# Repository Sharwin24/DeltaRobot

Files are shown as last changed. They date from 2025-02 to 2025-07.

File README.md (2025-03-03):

# DeltaRobot
Author: Sharwin Patil (*2025 MSR Winter Project*)

<div style="text-align: center;">
  Delta Robot Workspace
</div>

# ROS Package Structure

## Trajectory Generator
The `deltarobot_control` package is responsible for generating trajectories for the robot to follow. Currently, some hardcoded trajectories are baked into the package, but the package will be extended to offer parametric trajectory generation, resulting in position-velocity trajectories.

## Kinematics Solver
The `deltarobot_kinematics` package enables several kinematic capabilities for any delta robot. The package accepts a config file that specifies the robot's geometry, link lengths, and joint limits. Forward and Inverse Kinematics are implemented here as well as the Jacobian for creating joint-velocity trajectories from position trajectories.

## Motor Controller
The `deltarobot_motorcontrol` package is responsible for interfacing (using the hardware) with the 3 motors controlling the robot. This package implements
interfacing with dynamixel motors but can be extended to other motor types as long as the inter-node connections are maintained.

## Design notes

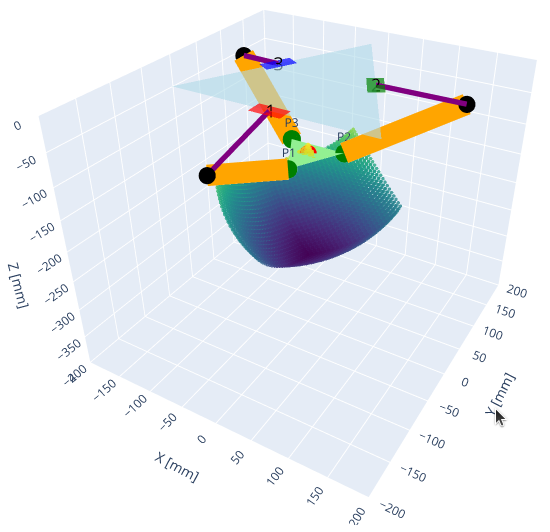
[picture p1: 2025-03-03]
images/workspace.png

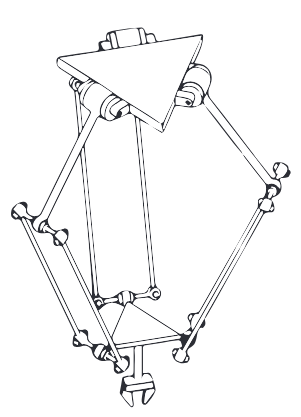
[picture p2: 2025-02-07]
images/delta_robot_modern_robotics.png

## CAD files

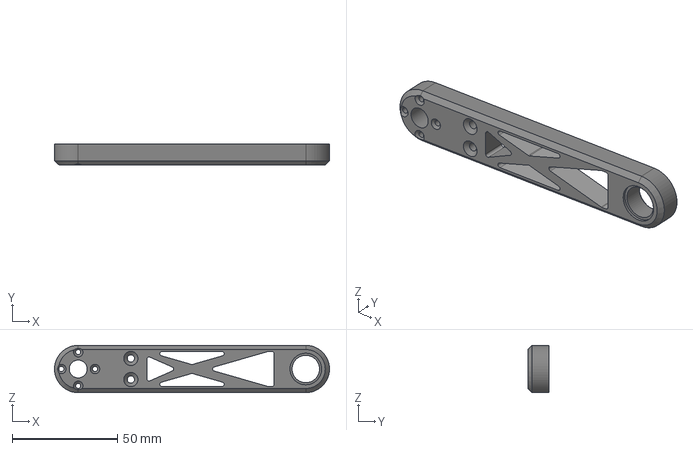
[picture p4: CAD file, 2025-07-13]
3D Printed Parts/Active Link.step
130.5 x 10.0 x 22.5 mm

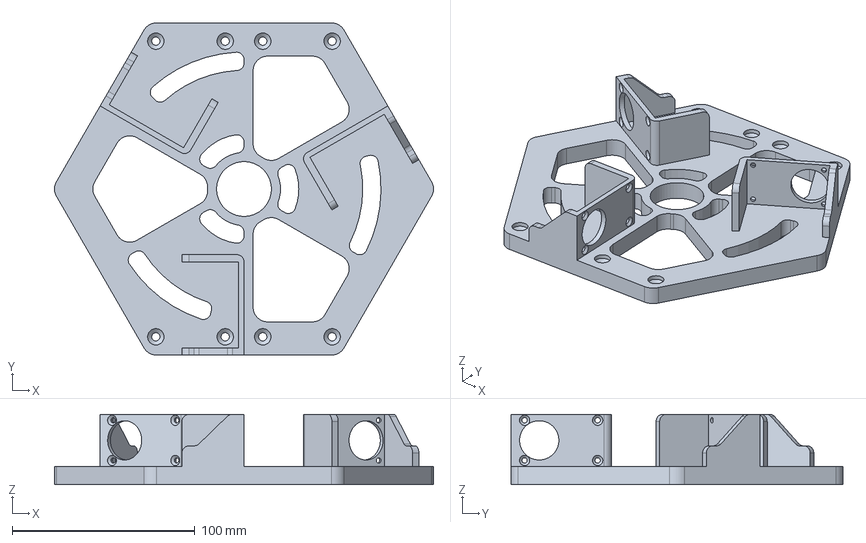
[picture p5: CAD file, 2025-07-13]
3D Printed Parts/Motor Base.step
207.5 x 181.9 x 38.5 mm

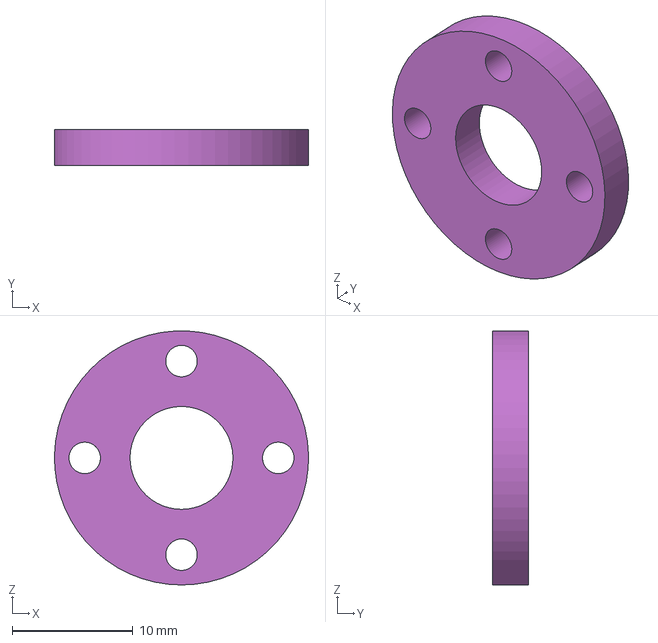
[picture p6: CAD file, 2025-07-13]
3D Printed Parts/Motor Spacer.step
21.0 x 3.00 x 21.0 mm

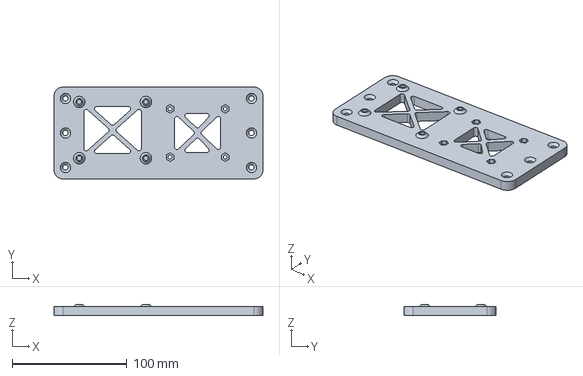
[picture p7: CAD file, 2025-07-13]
3D Printed Parts/Electronics Platform.step
181.9 x 80.0 x 10.0 mm

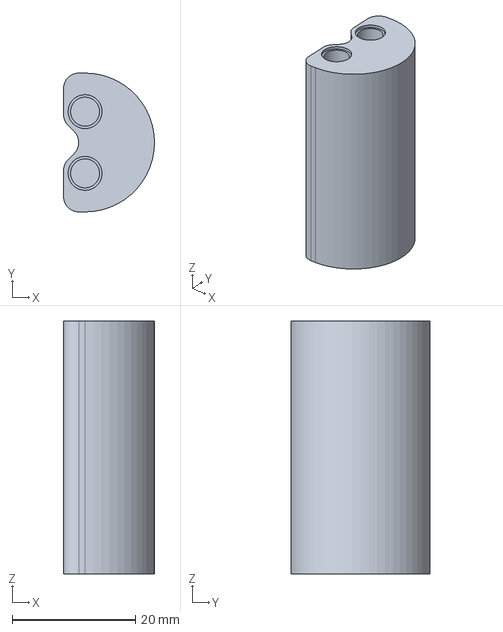
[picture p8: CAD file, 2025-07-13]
3D Printed Parts/Idler Cross Beam.step
14.8 x 22.5 x 41.0 mm

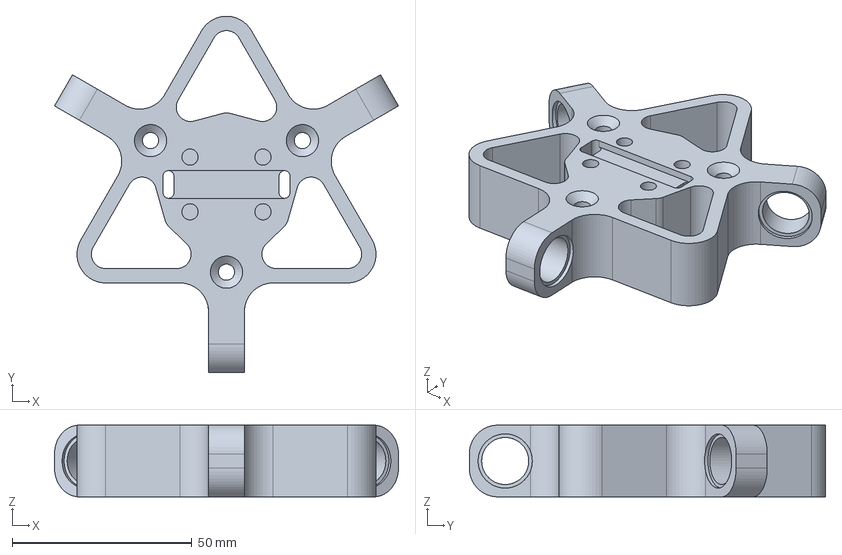
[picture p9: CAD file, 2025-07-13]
3D Printed Parts/End Effector Platform.step
95.8 x 99.3 x 20.0 mm

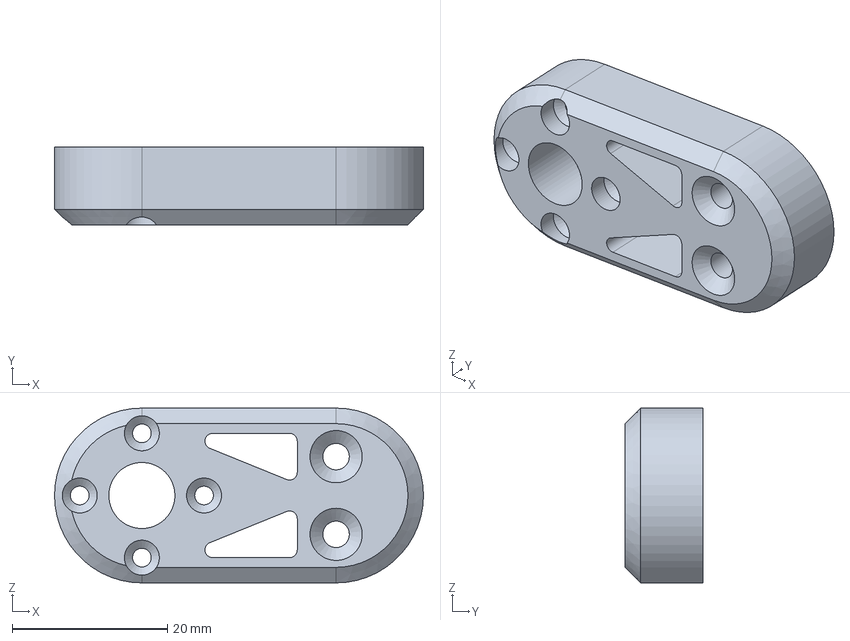
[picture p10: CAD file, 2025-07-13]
3D Printed Parts/Idler Link.step
47.5 x 10.0 x 22.5 mm

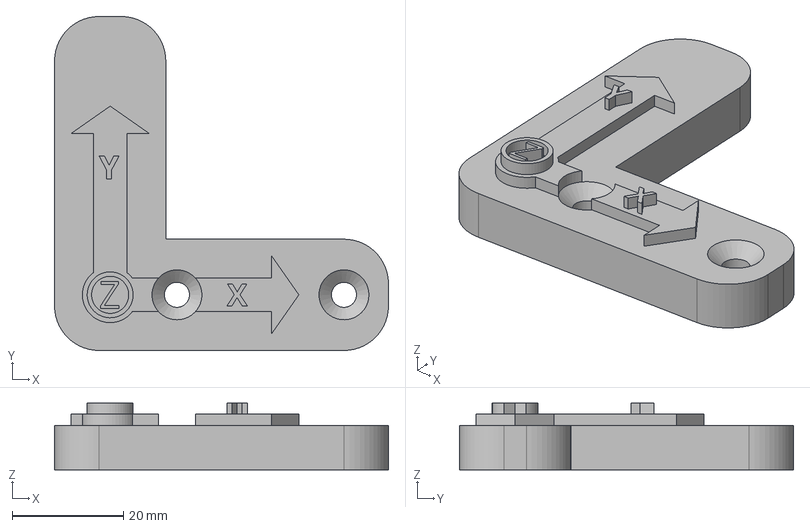
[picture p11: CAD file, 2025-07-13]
3D Printed Parts/Coordinate Axes.step
60.0 x 60.0 x 12.0 mm

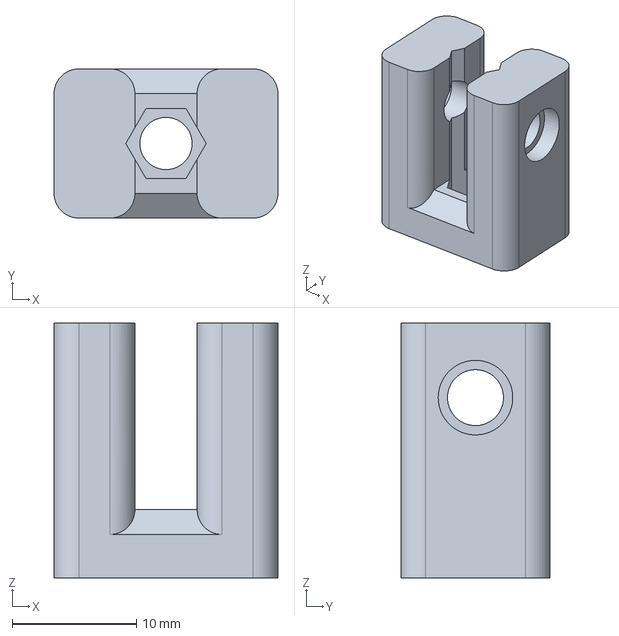
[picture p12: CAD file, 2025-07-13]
3D Printed Parts/Knee Bracket (Nut).step
18.0 x 12.0 x 20.5 mm

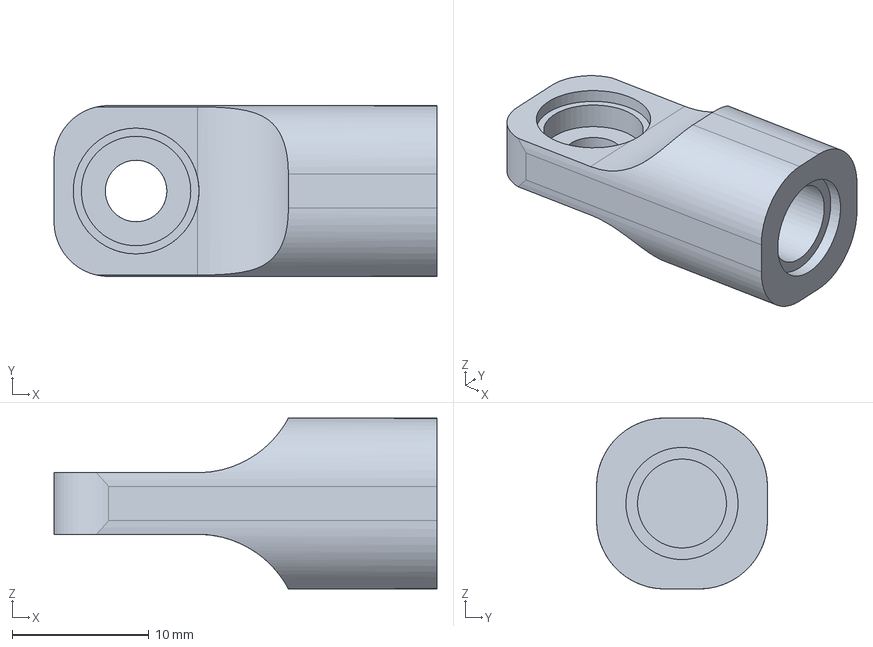
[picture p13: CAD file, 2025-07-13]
3D Printed Parts/Connecting Rod Swivel Joint.step
28.0 x 12.5 x 12.5 mm

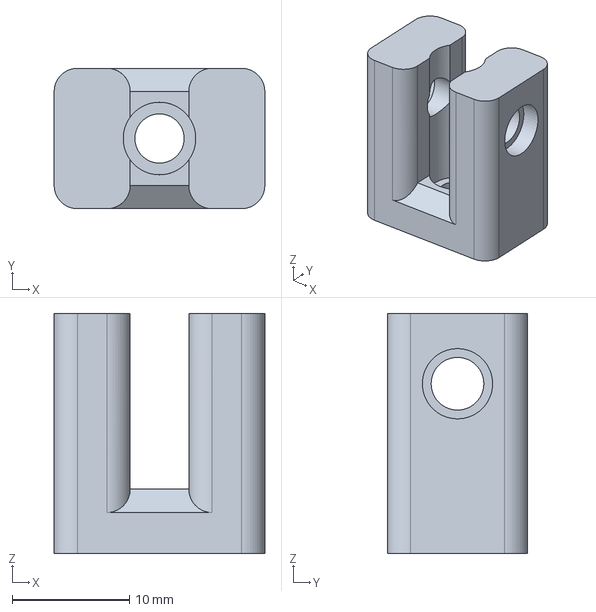
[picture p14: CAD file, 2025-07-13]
3D Printed Parts/Knee Bracket (Screw).step
18.0 x 12.0 x 20.5 mm

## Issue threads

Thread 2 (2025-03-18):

Filtered Sensor Data

Sharwin24, 2025-03-18:
https://github.com/user-attachments/assets/70047093-c119-4ee8-bd18-1d0791281004

An Alpha-Beta Filter was used to improve the measurements taken from the Time-of-Flight sensor and the temperature sensor on the BNO055 IMU. The filter's error was measured using the robot's kinematics as "ground truth" and landed in the ballpark of approximately 16mm of error in the Z direction. The error is and seems large but is more information available to the complementary filter using Forward Kinematics (measured in real-life to be accurate with approximately 1mm of error) to estimate the end effector position.

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

The parameters of the filter are passed into the ROS node in the `sensors_config.yaml` file and can be dynamically using `ros2 param set` to adjust the filter during operation.

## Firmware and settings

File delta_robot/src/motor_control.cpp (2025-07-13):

/// @file motor_control.cpp
/// @brief Motor Control Implementation for Delta Robot using Dynamixel X-Series Motors
/// @author Sharwin Patil
/// @date 2025-07-13
/// @version 2.0
///
/// PARAMETERS:
///   qos_depth (int8): The depth of the QoS queue for message reliability (default: 10)
///
/// PUBLISHERS:
///   ~/delta_motors/motor_position_feedback (deltarobot_interfaces::msg::DeltaJoints): Publishes real-time motor position feedback in radians
///   ~/delta_motors/motor_velocity_feedback (deltarobot_interfaces::msg::DeltaJointVels): Publishes real-time motor velocity feedback in rad/s
///
/// SUBSCRIBERS:
///   ~/delta_motors/set_joints (deltarobot_interfaces::msg::DeltaJoints): Subscribes to joint position commands to control motor positions
///   ~/delta_motors/set_joint_vels (deltarobot_interfaces::msg::DeltaJointVels): Subscribes to joint velocity commands to control motor velocities
///
/// SERVICES:
///   ~/delta_motors/set_joint_limits (deltarobot_interfaces::srv::SetJointLimits): Service to configure motor position and velocity limits
///
/// CLIENTS:
///   None

#include "motor_control.hpp"

// Control table address for X series(except XL - 320)
#define ADDR_OPERATING_MODE 11
#define ADDR_TORQUE_ENABLE 64
#define ADDR_GOAL_POSITION 116
#define ADDR_PRESENT_POSITION 132
#define ADDR_MIN_POSITION_LIMIT 48
#define ADDR_MAX_POSITION_LIMIT 52
#define ADDR_GOAL_VELOCITY 104
#define ADDR_PRESENT_VELOCITY 128
#define ADDR_VELOCITY_LIMIT 44
#define ADDR_LED 65

// 3 is for Position Control Mode, 1 is for Velocity Control Mode
#define POSITION_CTRL 3
#define VELOCITY_CTRL 1

// Protocol version
#define PROTOCOL_VERSION 2.0  // Default Protocol version of DYNAMIXEL X series.

// Default setting
#define BAUDRATE 115200  // Default Baudrate of DYNAMIXEL X series
#define DEVICE_NAME "/dev/ttyUSB0"  // [Linux]: "/dev/ttyUSB*", [Windows]: "COM*"

// Converting from degrees to motor position
#define UP_POS 3073.0f // [motor ticks]
#define THETA_MAX (M_PI / 2.0f) // [rad]
#define DOWN_POS 2048.0f // [motor ticks] this value is THETA_MAX in motor ticks
#define RAD_TO_MOTOR_TICKS ((DOWN_POS - UP_POS) / THETA_MAX)

// Converting from rad/s to rev/min
#define RAD_S_TO_REV_MIN (60.0f * (1.0f / (2.0f * M_PI)))
// The velocity limit range is (0 ~ 1023) where each unit is 0.229 rev/min
#define VEL_UNIT 0.229f // [rev/min]

DeltaMotorControl::DeltaMotorControl() : Node("delta_motor_control") {
  RCLCPP_INFO(this->get_logger(), "DeltaMotorControl Started");

  this->declare_parameter("qos_depth", 10);
  int8_t qos_depth = 10;
  this->get_parameter("qos_depth", qos_depth);

  const auto QOS_RKL10V =
    rclcpp::QoS(rclcpp::KeepLast(qos_depth)).reliable().durability_volatile();

  this->portHandler = dynamixel::PortHandler::getPortHandler(DEVICE_NAME);
  this->packetHandler = dynamixel::PacketHandler::getPacketHandler(PROTOCOL_VERSION);
  this->groupSyncWrite = new dynamixel::GroupSyncWrite(this->portHandler, this->packetHandler, ADDR_GOAL_POSITION, 4);

  // Initialize the port, baud rate, control mode
  this->initializeDynamixels();

  // Subscriber to receive position commands and write them to the motors
  this->delta_joints_sub = this->create_subscription<DeltaJoints>(
    "delta_motors/set_joints",
    QOS_RKL10V,
    [this](const DeltaJoints::SharedPtr msg) -> void
  {
    if (this->getControlMode() != POSITION_CTRL) { this->setControlMode(POSITION_CTRL); }
    std::array<uint32_t, 3> motor_positions = {
      convertToMotorPosition(msg->theta1),
      convertToMotorPosition(msg->theta2),
      convertToMotorPosition(msg->theta3)
    };

    // Clear the groupSyncWrite data
    this->groupSyncWrite->clearParam();

    // Position Value of X series is 4 byte data.
    // For AX & MX(1.0) use 2 byte data(uint16_t) for the Position Value.
    for (uint8_t i = 0; i < motor_positions.size(); i++) {
      // Create parameter for GroupSyncWrite
      uint8_t param_goal_position[4];
      param_goal_position[0] = DXL_LOBYTE(DXL_LOWORD(motor_positions[i]));
      param_goal_position[1] = DXL_HIBYTE(DXL_LOWORD(motor_positions[i]));
      param_goal_position[2] = DXL_LOBYTE(DXL_HIWORD(motor_positions[i]));
      param_goal_position[3] = DXL_HIBYTE(DXL_HIWORD(motor_positions[i]));

      if (!this->groupSyncWrite->addParam(i + 1, param_goal_position)) {
        RCLCPP_ERROR(this->get_logger(), "Failed to add param to groupSyncWrite");
      }
    }

    // Transmit all position commands at once
    int dxl_comm_result = this->groupSyncWrite->txPacket();
    if (dxl_comm_result != COMM_SUCCESS) {
      RCLCPP_ERROR(this->get_logger(), "GroupSyncWrite failed: %s", this->packetHandler->getTxRxResult(dxl_comm_result));
    }

    RCLCPP_DEBUG(
      this->get_logger(),
      "Motor Positions Set: (%d, %d, %d) [rad]",
      motor_positions[0],
      motor_positions[1],
      motor_positions[2]
    );
  }
  );

  this->delta_joint_vels_sub = this->create_subscription<DeltaJointVels>(
    "delta_motors/set_joint_vels",
    QOS_RKL10V,
    [this](const DeltaJointVels::SharedPtr msg) -> void
  {
    if (this->getControlMode() != VELOCITY_CTRL) { this->setControlMode(VELOCITY_CTRL); }
    std::array<int, 3> motor_vels = {
      this->convertToMotorVelocity(msg->theta1_vel),
      this->convertToMotorVelocity(msg->theta2_vel),
      this->convertToMotorVelocity(msg->theta3_vel)
    };
    RCLCPP_INFO(
      this->get_logger(),
      "Motor Velocities Set: (%d, %d, %d) [rev/min]",
      motor_vels[0],
      motor_vels[1],
      motor_vels[2]
    );

    // Clear the groupSyncWrite data
    this->groupSyncWrite->clearParam();

    // Velocity Value of X series is 4 byte data.
    // For AX & MX(1.0) use 2 byte data(uint16_t) for the Velocity Value.
    for (uint8_t i = 0; i < 3; i++) {
      // Create parameter for GroupSyncWrite
      uint8_t param_goal_velocity[4];
      param_goal_velocity[0] = DXL_LOBYTE(DXL_LOWORD(motor_vels[i]));
      param_goal_velocity[1] = DXL_HIBYTE(DXL_LOWORD(motor_vels[i]));
      param_goal_velocity[2] = DXL_LOBYTE(DXL_HIWORD(motor_vels[i]));
      param_goal_velocity[3] = DXL_HIBYTE(DXL_HIWORD(motor_vels[i]));

      if (!this->groupSyncWrite->addParam(i + 1, param_goal_velocity)) {
        RCLCPP_ERROR(this->get_logger(), "Failed to add param to groupSyncWrite");
      }
    }

    // Transmit all velocity commands at once
    int dxl_comm_result = this->groupSyncWrite->txPacket();
    if (dxl_comm_result != COMM_SUCCESS) {
      RCLCPP_ERROR(this->get_logger(), "GroupSyncWrite failed: %s", this->packetHandler->getTxRxResult(dxl_comm_result));
    }

    /**
     * Manually publish zero velocity afterwards to stop the motors
     */
    this->groupSyncWrite->clearParam();
    for (uint8_t i = 0; i < 3; i++) {
      // Create parameter for GroupSyncWrite
      uint8_t param_goal_velocity[4];
      param_goal_velocity[0] = DXL_LOBYTE(DXL_LOWORD(0));
      param_goal_velocity[1] = DXL_HIBYTE(DXL_LOWORD(0));
      param_goal_velocity[2] = DXL_LOBYTE(DXL_HIWORD(0));
      param_goal_velocity[3] = DXL_HIBYTE(DXL_HIWORD(0));

      if (!this->groupSyncWrite->addParam(i + 1, param_goal_velocity)) {
        RCLCPP_ERROR(this->get_logger(), "Failed to add param to groupSyncWrite");
      }
    }

    // Transmit the stop command
    dxl_comm_result = this->groupSyncWrite->txPacket();
    if (dxl_comm_result != COMM_SUCCESS) {
      RCLCPP_ERROR(this->get_logger(), "GroupSyncWrite failed: %s", this->packetHandler->getTxRxResult(dxl_comm_result));
    }

    RCLCPP_DEBUG(
      this->get_logger(),
      "Motor Velocities Set: (%f, %f, %f) [rad/s]",
      msg->theta1_vel,
      msg->theta2_vel,
      msg->theta3_vel
    );
  }
  );

  // Service to set the joint limits
  this->set_joint_limits_server = create_service<SetJointLimits>(
    "delta_motors/set_joint_limits",
    [this](
      const std::shared_ptr<SetJointLimits::Request> request,
      std::shared_ptr<SetJointLimits::Response> response) -> void
  {
    // Convert request data into motor position and velocity values
    uint32_t motor_min = this->convertToMotorPosition(request->min_rad);
    uint32_t motor_max = this->convertToMotorPosition(request->max_rad);
    int max_vel = this->convertToMotorVelocity(request->max_vel_rad_s);
    int dxl_comm_result = COMM_TX_FAIL;

    this->disableTorque();

    // Set Position Limits on MIN_POSITION_LIMIT and MAX_POSITION_LIMIT
    // Set Velocity Limit on VELOCITY_LIMIT
    for (uint8_t i = 1; i <= 3; i++) {
      uint8_t dxl_error = 0;
      dxl_comm_result = this->packetHandler->write4ByteTxRx(
        this->portHandler,
        i,
        ADDR_MIN_POSITION_LIMIT,
        motor_min,
        &dxl_error
      );
      if (dxl_comm_result != COMM_SUCCESS) {
        RCLCPP_ERROR(this->get_logger(), "Failed to set Min Position Limit: %d", dxl_error);
      }

      dxl_comm_result = this->packetHandler->write4ByteTxRx(
        this->portHandler,
        i,
        ADDR_MAX_POSITION_LIMIT,
        motor_max,
        &dxl_error
      );
      if (dxl_comm_result != COMM_SUCCESS) {
        RCLCPP_ERROR(this->get_logger(), "Failed to set Max Position Limit: %d", dxl_error);
      }

      dxl_comm_result = this->packetHandler->write4ByteTxRx(
        this->portHandler,
        i,
        ADDR_VELOCITY_LIMIT,
        max_vel,
        &dxl_error
      );
      if (dxl_comm_result != COMM_SUCCESS) {
        RCLCPP_ERROR(this->get_logger(), "Failed to set Velocity Limit: %d", dxl_error);
      }
    }

    RCLCPP_INFO(
      this->get_logger(),
      "Joint Limits Set: Position [%f, %f] [rad], Velocity: %.2f [rad/s]", request->min_rad, request->max_rad, request->max_vel_rad_s
    );

    this->enableTorque();
    response->success = true;
  }
  );

  // Publishers for motor positions and velocities
  this->motor_positions_pub = this->create_publisher<DeltaJoints>("delta_motors/motor_position_feedback", 10);
  this->motor_velocities_pub = this->create_publisher<DeltaJointVels>("delta_motors/motor_velocity_feedback", 10);

  // Timer to publish the motor positions and velocities
  const double feedback_freq = 25.0; // [Hz]
  this->motor_feedback_timer = this->create_wall_timer(
    std::chrono::duration<double>(1.0 / feedback_freq),
    [this]() -> void
  {
    // Array of Motor Positions
    std::array<int, 3> motor_positions = {0, 0, 0};

    for (uint8_t i = 1; i <= motor_positions.size(); i++) {
      uint8_t dxl_error = 0;
      int dxl_comm_result = COMM_TX_FAIL;
      // Read Present Position (length : 4 bytes) and Convert uint32 -> int32
      // When reading 2 byte data from AX / MX(1.0), use read2ByteTxRx() instead.
      dxl_comm_result = this->packetHandler->read4ByteTxRx(
        this->portHandler,
        i,
        ADDR_PRESENT_POSITION,
        reinterpret_cast<uint32_t*>(&motor_positions[i - 1]),
        &dxl_error
      );
      // Error Handling
      if (dxl_comm_result != COMM_SUCCESS) {
        RCLCPP_INFO(this->get_logger(), "%s", this->packetHandler->getTxRxResult(dxl_comm_result));
      } else if (dxl_error != 0) {
        RCLCPP_INFO(this->get_logger(), "%s", this->packetHandler->getRxPacketError(dxl_error));
      }
    }

    // Convert positions from dynamixel units to radians
    float theta1 = convertToRadians(motor_positions[0]);
    float theta2 = convertToRadians(motor_positions[1]);
    float theta3 = convertToRadians(motor_positions[2]);

    RCLCPP_DEBUG(
      this->get_logger(),
      "Motor Positions: (%d, %d, %d) [motor ticks] -> (%f, %f, %f) [rad]",
      motor_positions[0], motor_positions[1], motor_positions[2],
      theta1, theta2, theta3
    );

    // Array of Motor Velocities
    std::array<int, 3> motor_velocities = {0, 0, 0};

    for (uint8_t i = 1; i <= motor_velocities.size(); i++) {
      uint8_t dxl_error = 0;
      int dxl_comm_result = COMM_TX_FAIL;
      // Read Present Velocity (length : 4 bytes) and Convert uint32 -> int32
      // When reading 2 byte data from AX / MX(1.0), use read2ByteTxRx() instead.
      dxl_comm_result = this->packetHandler->read4ByteTxRx(
        this->portHandler,
        i,
        ADDR_PRESENT_VELOCITY,
        reinterpret_cast<uint32_t*>(&motor_velocities[i - 1]),
        &dxl_error
      );
      // Error Handling
      if (dxl_comm_result != COMM_SUCCESS) {
        RCLCPP_INFO(this->get_logger(), "%s", this->packetHandler->getTxRxResult(dxl_comm_result));
      } else if (dxl_error != 0) {
        RCLCPP_INFO(this->get_logger(), "%s", this->packetHandler->getRxPacketError(dxl_error));
      }
    }

    // Convert velocities from dynamixel units to rev/min
    for (uint8_t i = 0; i < motor_velocities.size(); i++) {
      motor_velocities[i] = motor_velocities[i] * VEL_UNIT;
    }

    RCLCPP_DEBUG(
      this->get_logger(),
      "Motor Velocities: (%d, %d, %d) [rev/min]",
      motor_velocities[0], motor_velocities[1], motor_velocities[2]
    );

    // Publish the motor positions and velocities
    auto motor_positions_msg = DeltaJoints();
    auto motor_velocities_msg = DeltaJointVels();
    motor_positions_msg.header.stamp = this->now();
    motor_velocities_msg.header.stamp = this->now();
    motor_positions_msg.theta1 = theta1;
    motor_positions_msg.theta2 = theta2;
    motor_positions_msg.theta3 = theta3;
    motor_velocities_msg.theta1_vel = motor_velocities[0];
    motor_velocities_msg.theta2_vel = motor_velocities[1];
    motor_velocities_msg.theta3_vel = motor_velocities[2];

    this->motor_positions_pub->publish(motor_positions_msg);
    this->motor_velocities_pub->publish(motor_velocities_msg);
  }
  );
}

DeltaMotorControl::~DeltaMotorControl() {
  this->disableTorque();
  // Turn off the LED
  uint8_t dxl_error = 0;
  this->packetHandler->write1ByteTxRx(
    this->portHandler,
    BROADCAST_ID,
    ADDR_LED,
    0,
    &dxl_error
  );
  this->portHandler->closePort();
  delete this->portHandler;
  delete this->packetHandler;
  delete this->groupSyncWrite;

}

void DeltaMotorControl::setControlMode(uint8_t ctrl_mode) {
  uint8_t dxl_error = 0;
  int dxl_comm_result = COMM_TX_FAIL;

  // Set the Operating Mode
  dxl_comm_result = this->packetHandler->write1ByteTxRx(
    this->portHandler,
    BROADCAST_ID,
    ADDR_OPERATING_MODE,
    ctrl_mode,
    &dxl_error
  );

  if (dxl_comm_result != COMM_SUCCESS) {
    RCLCPP_ERROR(this->get_logger(), "Failed to set Operating Mode: %d", dxl_error);
  } else {
    RCLCPP_INFO(this->get_logger(), "Succeeded to set Operating Mode (%s)", (ctrl_mode == POSITION_CTRL) ? "Position Control" : "Velocity Control");
  }

  // Save the control mode
  this->control_mode = ctrl_mode;
}

void DeltaMotorControl::initializeDynamixels() {
  int dxl_comm_result = COMM_TX_FAIL;
  uint8_t dxl_error = 0;

  // Open Serial Port
  if (this->portHandler->openPort()) {
    RCLCPP_INFO(this->get_logger(), "Succeeded to open the port (%s)", this->portHandler->getPortName());
  } else {
    RCLCPP_ERROR(this->get_logger(), "Failed to open the port!");
  }

  // Set the baudrate of the serial port (use DYNAMIXEL Baudrate)
  if (this->portHandler->setBaudRate(BAUDRATE)) {
    RCLCPP_INFO(this->get_logger(), "Succeeded to set the baudrate (%d)", this->portHandler->getBaudRate());
  } else {
    RCLCPP_ERROR(this->get_logger(), "Failed to set the baudrate!");
  }

  this->setControlMode(POSITION_CTRL);

  // Set LED of DYNAMIXEL
  dxl_comm_result = this->packetHandler->write1ByteTxRx(
    this->portHandler,
    BROADCAST_ID,
    ADDR_LED,
    1,
    &dxl_error
  );

  if (dxl_comm_result != COMM_SUCCESS) {
    RCLCPP_ERROR(this->get_logger(), "Failed to set LED.");
  } else {
    RCLCPP_INFO(this->get_logger(), "Succeeded to set Motor LED.");
  }

  this->enableTorque();
}

void DeltaMotorControl::disableTorque() {
  uint8_t dxl_error = 0;
  // Disable the torque before changing the control mode
  int dxl_comm_result = this->packetHandler->write1ByteTxRx(
    this->portHandler,
    BROADCAST_ID,
    ADDR_TORQUE_ENABLE,
    0,
    &dxl_error
  );

  if (dxl_comm_result != COMM_SUCCESS) {
    RCLCPP_ERROR(this->get_logger(), "Failed to disable torque: %d", dxl_error);
  } else {
    RCLCPP_INFO(this->get_logger(), "Succeeded to disable torque.");
  }
}

void DeltaMotorControl::enableTorque() {
  uint8_t dxl_error = 0;
  // Enable the torque after changing the control mode
  int dxl_comm_result = this->packetHandler->write1ByteTxRx(
    this->portHandler,
    BROADCAST_ID,
    ADDR_TORQUE_ENABLE,
    1,
    &dxl_error
  );

  if (dxl_comm_result != COMM_SUCCESS) {
    RCLCPP_ERROR(this->get_logger(), "Failed to enable torque: %d", dxl_error);
  } else {
    RCLCPP_INFO(this->get_logger(), "Succeeded to enable torque.");
  }
}

float DeltaMotorControl::convertToRadians(int motor_pos) {
  // Convert motor position [0, 4096) to theta [rad]
  return (motor_pos - UP_POS) / RAD_TO_MOTOR_TICKS;
}

uint32_t DeltaMotorControl::convertToMotorPosition(float theta) {
  // Convert theta [rad] to motor position [0, 4096)
  // 2048 is the "zero" position and is when the link is at pi/2 radians (90 deg)
  // 2800 is the "up" position when the link is at 0 radians (0 deg)
  // theta = 0 -> 2800; theta = pi/2 -> 2048; theta = pi/4 -> 2424 (halfway between 2800 and 2048)
  float motor_pos = RAD_TO_MOTOR_TICKS * theta + UP_POS;
  return static_cast<uint32_t>(motor_pos);
}

int DeltaMotorControl::convertToMotorVelocity(float theta_vel) {
  // Convert theta_vel [rad/s] to motor velocity [rev/min]
  float rpm = RAD_S_TO_REV_MIN * theta_vel;
  // Convert motor velocity [rev/min] to the appropriate value
  return static_cast<int>(rpm / VEL_UNIT);
}

int main(int argc, char* argv[]) {
  rclcpp::init(argc, argv);
  rclcpp::spin(std::make_shared<DeltaMotorControl>());
  rclcpp::shutdown();
  return 0;
}

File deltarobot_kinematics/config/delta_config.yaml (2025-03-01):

/**:
  ros__parameters:
    base_triangle_side_length: 261.30642 # [mm]
    end_effector_side_length: 73.48076 # [mm]
    active_link_length: 108.0 # [mm]
    passive_link_length: 174.0 # [mm]
    passive_link_width: 42.8 # [mm]
    joint_min: 0.174532925199 # [rad] (10 deg)
    joint_max: 1.4835298642 # [rad] (85 deg)

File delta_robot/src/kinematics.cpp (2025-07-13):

/// @file kinematics.cpp
/// @brief Kinematics Implementation for Delta Robot
/// @author Sharwin Patil
/// @date 2025-07-13
/// @version 2.0
/// @cite https://hypertriangle.com/~alex/delta-robot-tutorial/
///
/// PARAMETERS:
///   base_triangle_side_length (float64): The side length of the equilateral triangle defining the base [mm]
///   active_link_length (float64): The center distance (joint to joint) of the actuated links [mm]
///   passive_link_length (float64): The center distance (joint to joint) of the passive links [mm]
///   passive_link_width (float64): The width of the passive links [mm]
///   end_effector_side_length (float64): The side length of the equilateral triangle defining the end effector [mm]
///   joint_min (float64): The minimum joint angle [rad]
///   joint_max (float64): The maximum joint angle [rad]
///   max_joint_velocity (float64): The maximum joint velocity [rad/s]
///   robot_config_freq (float64): The frequency at which the robot configuration is published [Hz]
///
/// PUBLISHERS:
///   ~/delta_robot/robot_config (deltarobot_interfaces::msg::RobotConfig): Publishes the current robot configuration including joint angles/velocities and end effector position
///
/// SUBSCRIBERS:
///   ~/delta_motors/motor_position_feedback (deltarobot_interfaces::msg::DeltaJoints): Subscribes to the current joint angles of the delta robot
///   ~/delta_motors/motor_velocity_feedback (deltarobot_interfaces::msg::DeltaJointVels): Subscribes to the current joint velocities of the delta robot
///
/// SERVICES:
///   ~/delta_fk (deltarobot_interfaces::srv::DeltaFK): Computes the end effector position given the joint angles (forward kinematics)
///   ~/delta_ik (deltarobot_interfaces::srv::DeltaIK): Computes the joint angles given the end effector position (inverse kinematics)
///   ~/convert_to_joint_trajectory (deltarobot_interfaces::srv::ConvertToJointTrajectory): Converts an end effector trajectory to a joint trajectory
///   ~/convert_to_joint_vel_trajectory (deltarobot_interfaces::srv::ConvertToJointVelTrajectory): Converts an end effector velocity trajectory to a joint velocity trajectory
///
/// CLIENTS:
///  ~/delta_motors/set_joint_limits (deltarobot_interfaces::srv::SetJointLimits): Client to set the joint limits for the delta robot motors


#include "rclcpp/rclcpp.hpp"
#include "rclcpp/node_options.hpp"
#include "geometry_msgs/msg/point.hpp"
#include "kinematics.hpp"
#include <vector>
#include <math.h>
#include <eigen3/Eigen/Dense>

const float sqrt3 = sqrt(3.0);
const float sin120 = sqrt3 / 2.0;
constexpr float cos120 = -0.5;
const float tan60 = sqrt3;
constexpr float sin30 = 0.5;
const float tan30 = 1 / sqrt3;

template<typename T>
using ServiceResponseFuture = typename rclcpp::Client<T>::SharedFuture;

DeltaKinematics::DeltaKinematics() : Node("delta_kinematics") {
  RCLCPP_INFO(this->get_logger(), "DeltaKinematics Started");

  // Declare parameters
  this->declare_parameter("base_triangle_side_length", 200.0);
  this->declare_parameter("end_effector_side_length", 100.0);
  this->declare_parameter("active_link_length", 100.0);
  this->declare_parameter("passive_link_length", 100.0);
  this->declare_parameter("passive_link_width", 30.0);
  this->declare_parameter("joint_min", 0.0);
  this->declare_parameter("joint_max", M_PI / 2.0);
  this->declare_parameter("max_joint_velocity", 1.0);
  this->declare_parameter("robot_config_freq", 10.0);

  // Save parameters from yaml for easy access
  this->SB = this->get_parameter("base_triangle_side_length").as_double();
  this->SP = this->get_parameter("end_effector_side_length").as_double();
  this->AL = this->get_parameter("active_link_length").as_double();
  this->PL = this->get_parameter("passive_link_length").as_double();
  this->PW = this->get_parameter("passive_link_width").as_double();
  this->JMin = this->get_parameter("joint_min").as_double();
  this->JMax = this->get_parameter("joint_max").as_double();
  this->MaxJointVel = this->get_parameter("max_joint_velocity").as_double();
  const double robot_config_freq = this->get_parameter("robot_config_freq").as_double();

  // Create FK and IK servers
  this->delta_fk_server = create_service<DeltaFK>(
    "delta_kinematics/delta_fk",
    std::bind(&DeltaKinematics::forwardKinematics, this, std::placeholders::_1, std::placeholders::_2)
  );

  this->delta_ik_server = create_service<DeltaIK>(
    "delta_kinematics/delta_ik",
    std::bind(&DeltaKinematics::inverseKinematics, this, std::placeholders::_1, std::placeholders::_2)
  );

  // Create ConvertToJointTrajectory server
  this->convert_to_joint_trajectory_server = create_service<ConvertToJointTrajectory>(
    "delta_kinematics/convert_to_joint_trajectory",
    std::bind(&DeltaKinematics::convertToJointTrajectory, this, std::placeholders::_1, std::placeholders::_2)
  );

  // Create ConvertToJointVelTrajectory server
  this->convert_to_joint_vel_trajectory_server = create_service<ConvertToJointVelTrajectory>(
    "delta_kinematics/convert_to_joint_vel_trajectory",
    std::bind(&DeltaKinematics::convertToJointVelTrajectory, this, std::placeholders::_1, std::placeholders::_2)
  );

  // Wait for the set_joint_limits service to be available
  this->set_joint_limits_client = create_client<SetJointLimits>("delta_motors/set_joint_limits");
  while (!this->set_joint_limits_client->wait_for_service(std::chrono::seconds(2))) {
    if (!rclcpp::ok()) {
      RCLCPP_ERROR(this->get_logger(), "Interrupted while waiting for the service. Exiting.");
      return;
    }
    RCLCPP_INFO(this->get_logger(), "Service not available, waiting again...");
  }

  // Create RobotConfig Publisher
  this->robot_config_publisher = create_publisher<RobotConfig>("delta_robot/robot_config", 10);

  // Create subscribers for motor positions and velocities
  this->motor_positions_sub = create_subscription<DeltaJoints>("delta_motors/motor_position_feedback", 10,
    [this](const DeltaJoints::SharedPtr msg) -> void { // Update the motor positions
    this->robot_state.theta1 = msg->theta1;
    this->robot_state.theta2 = msg->theta2;
    this->robot_state.theta3 = msg->theta3;
  }
  );

  this->motor_velocities_sub = create_subscription<DeltaJointVels>("delta_motors/motor_velocity_feedback", 10,
    [this](const DeltaJointVels::SharedPtr msg) -> void { // Update the motor velocities
    this->robot_state.theta1_vel = msg->theta1_vel;
    this->robot_state.theta2_vel = msg->theta2_vel;
    this->robot_state.theta3_vel = msg->theta3_vel;
  }
  );

  // Call the set_joint_limits service and set the joint limits
  auto set_joint_limits_request = std::make_shared<SetJointLimits::Request>();
  set_joint_limits_request->min_rad = this->JMin;
  set_joint_limits_request->max_rad = this->JMax;
  set_joint_limits_request->max_vel_rad_s = this->MaxJointVel;
  auto result = this->set_joint_limits_client->async_send_request(set_joint_limits_request);
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

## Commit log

2025-01-25 Started a python kinematics file
2025-01-30 Created structure for kinematics
2025-02-04 Wrote stubs for Kinematics
2025-02-04 Gutted Dynamixel dependencies from kinematics
2025-02-04 Created launch file
    [motor_control.launch.xml]
2025-02-04 Renamed launch file and moved SDK out of kinematics
2025-02-04 Wrote motor control node with subscriber
2025-02-05 Shortened lambdas with for loops and wrote launch file
    [motor_control.launch.xml]
2025-02-05 Launch file launches kinematics and motor control
2025-02-07 Created kinematics notebook
2025-02-07 Inverse Kinematics Implementation in Notebook
2025-02-09 Updated Robot Constants from CAD measurements
2025-02-12 Switched to plotly
2025-02-16 Adding guards to kinematics
2025-02-16 Pulled in open source c++ kinematics
2025-02-18 Implemented different kinematics
2025-02-19 Fixed Kinematics!
2025-02-19 Renamed msgs and srvs types and fixed bugs that used them
    [delta_motor_control.cpp, kinematics.cpp]
2025-02-19 Fixed motor tick conversion
    [delta_motor_control.cpp]
2025-02-19 Included joint limits in kinematics files
2025-02-19 Found min and max motor ticks from testing
2025-02-25 Added kalman filter project for sensors
2025-02-25 Sensor package created
2025-02-25 Changed motor control to group sync instead of independent IDs
2025-02-25 Fixed Dynamixel ID in group sync
    [delta_motor_control.cpp]
2025-02-26 publishing to joints after calculating ik
2025-02-26 Tested IK for joints
2025-02-27 New service to create joint trajectory
2025-02-27 publishing to motors and moving the robot!
2025-02-27 launch the sensors as well
2025-03-01 Implemented jacobian and velocity trajejectories
2025-03-01 Wrote a section about converting the position to velocity trajectory in C++
2025-07-13 Added 3D Printed Parts
    [Active Link.step, Connecting Rod Swivel Joint.step, Coordinate Axes.step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]
2025-07-13 Cleanup and creating folders for files
    [random_points.csv, scan_trajectory.csv, workspace_points.csv]
